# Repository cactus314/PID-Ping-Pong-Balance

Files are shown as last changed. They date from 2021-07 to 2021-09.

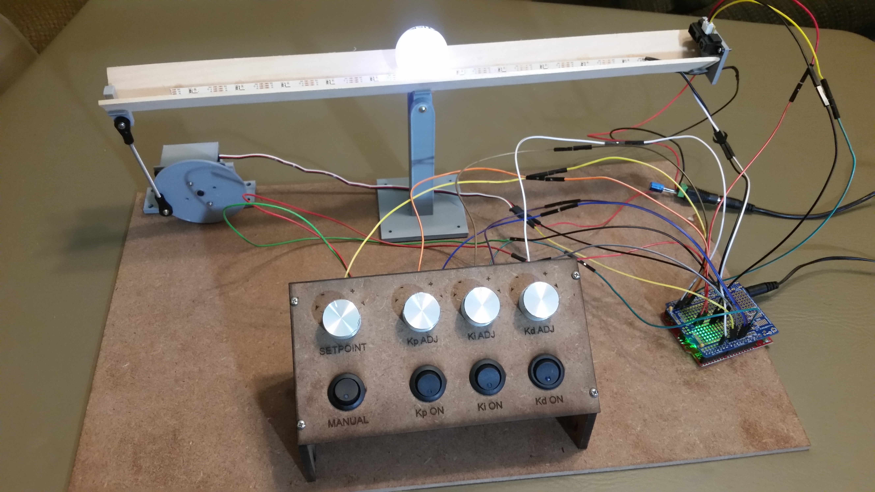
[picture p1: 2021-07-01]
20200308_224231.jpg

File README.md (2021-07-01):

# PID-Ping-Pong-Balance
A PID control demonstration unit, based on a project by Electronoob: http://electronoobs.com/eng_arduino_tut100.php

This project uses an IR sensor to detect the location of a ping-pong ball along a rail and a servo-motor as an actuator to position the angle of the rail to maintain the ball at a given setpoint using hardcoded PID parameters.  The setpoint and P, I, and D gains can also be overridden in "Manual" mode.

A demonstration and explanation of the project is available in the following video:
https://youtu.be/-h1OtBgMqcE

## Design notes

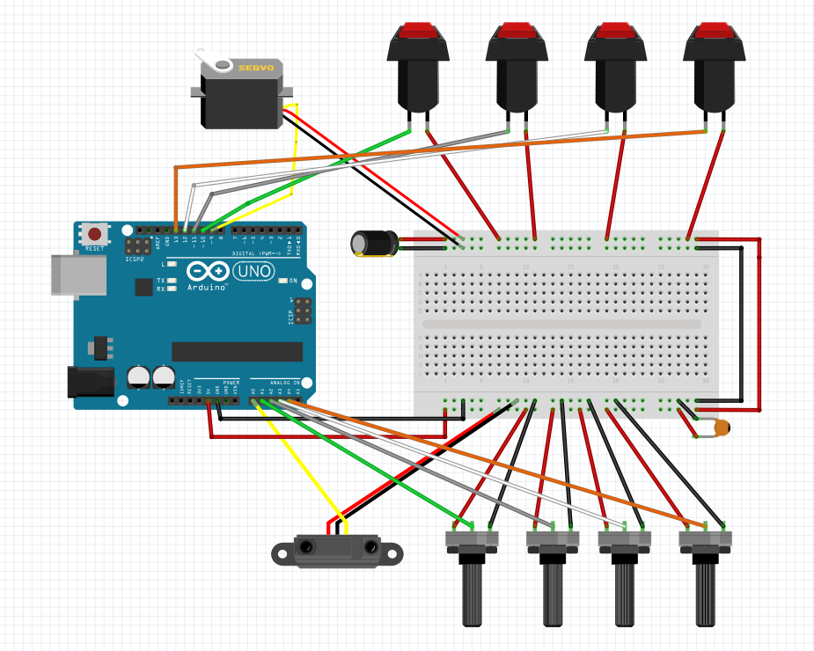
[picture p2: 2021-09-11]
PingPongBalance Fritzing Screenshot.png

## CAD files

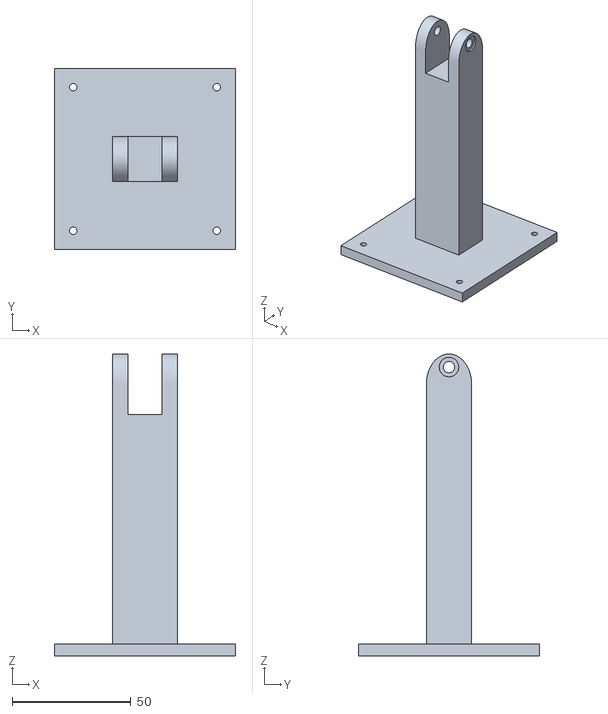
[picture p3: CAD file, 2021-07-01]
PingPongBalanceSTLs/pivot pillar.stl
76.2 x 76.2 x 127.0

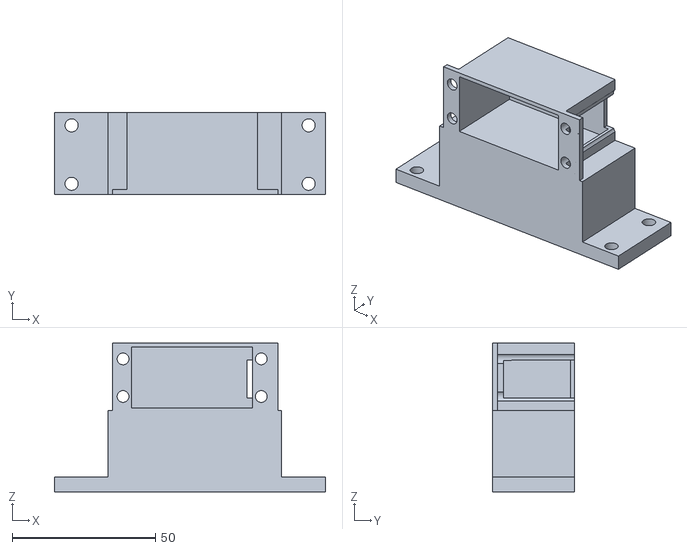
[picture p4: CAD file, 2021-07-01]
PingPongBalanceSTLs/Servo_support_Electronoob.stl
94.6 x 28.7 x 51.9

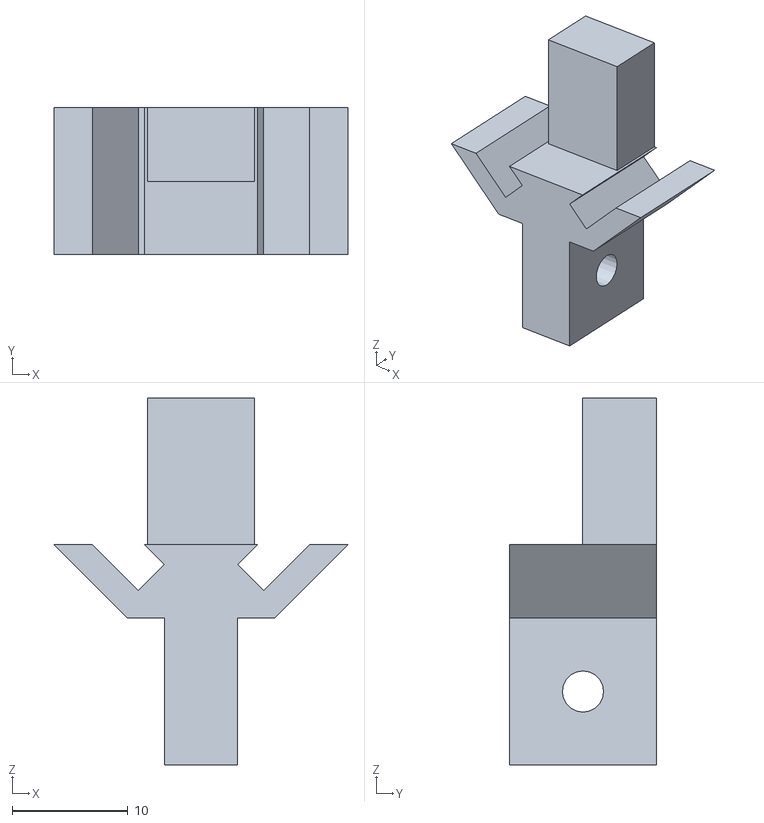
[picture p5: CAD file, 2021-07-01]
PingPongBalanceSTLs/servo end clip.stl
25.4 x 12.7 x 31.7

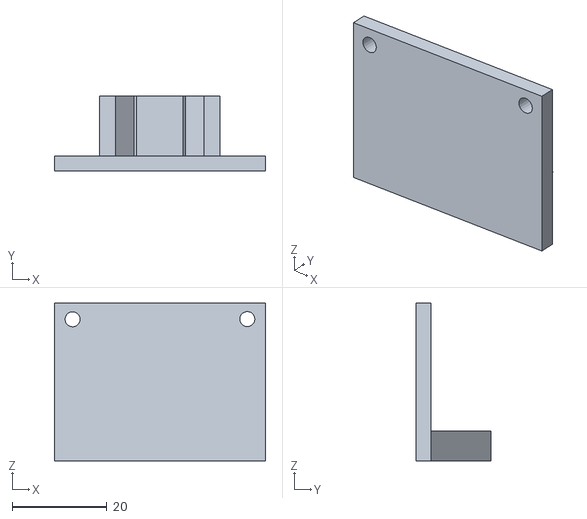
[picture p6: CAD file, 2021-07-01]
PingPongBalanceSTLs/sharp sensor clip.stl
44.6 x 15.9 x 33.3

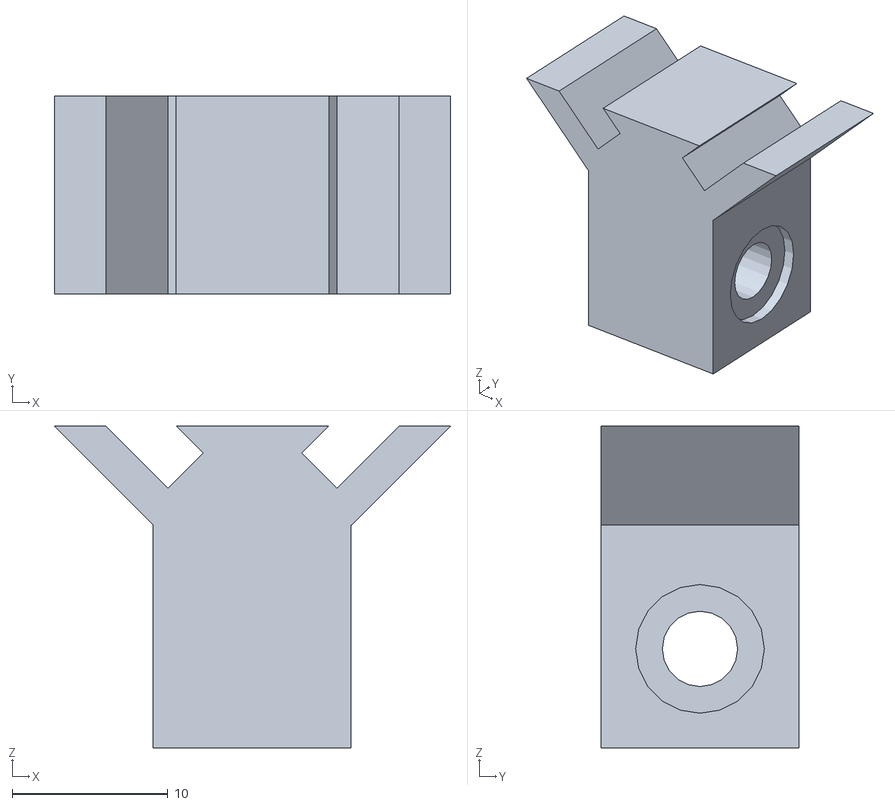
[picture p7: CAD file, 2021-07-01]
PingPongBalanceSTLs/pivot clip.stl
25.4 x 12.7 x 20.6

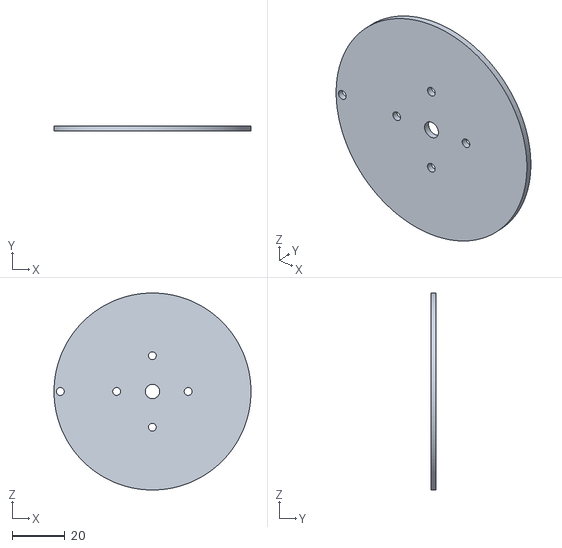
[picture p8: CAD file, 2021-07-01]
PingPongBalanceSTLs/Disc2_Electronoob.stl
74.4 x 2.00 x 74.4

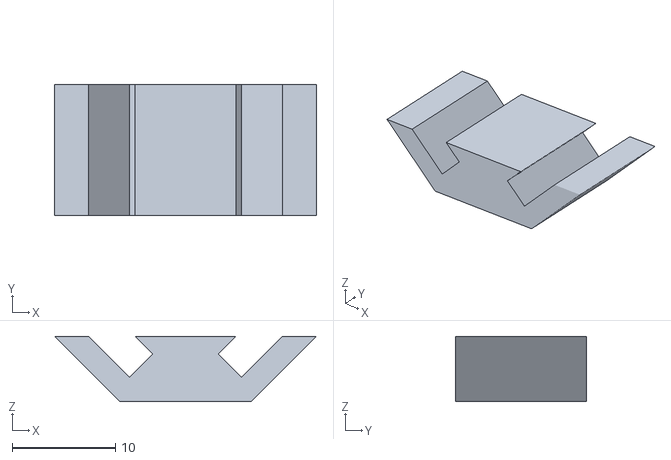
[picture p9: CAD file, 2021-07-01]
PingPongBalanceSTLs/basic clip.stl
25.4 x 12.7 x 6.35

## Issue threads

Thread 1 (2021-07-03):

Need 'ball stop' close to IR sensor

cactus314, 2021-07-03:
The Sharp IR sensor gives bad readings when the ping-pong ball is too close (perhaps 5cm or less).  There should be a mechanical stop so that the ball doesn't so close to the sensor when oscillating back and forth during proportional control.

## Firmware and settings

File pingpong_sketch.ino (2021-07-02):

/*Ping Pong PID Balance
 * March 2020
 * P Ferrell
 * Inspired by: http://www.electronoobs.com/eng_arduino_tut100.php
 * 
 * 
 * */
 
#include <SharpIR.h>  //https://www.makerguides.com/sharp-gp2y0a21yk0f-ir-distance-sensor-arduino-tutorial/
#include <Servo.h>
#include <Adafruit_NeoPixel.h>  //https://learn.adafruit.com/adafruit-neopixel-uberguide/arduino-library-use

#define irPin A0  // IR sensor attached on pin A0
#define irModel 1080  // Sharp IR sensor model GP2Y0A21YK0F
SharpIR SharpIR(irPin,irModel);

#define servoPin 9  // servo motor attached on pin 9
Servo myServo;
int servoDefault = 110; // nominal default position for servo to hold balance rails level
int servoLowerLimit = 20;
int servoUpperLimit = 150;
int servoCorrection = 30;  // value to offset servo if needed

#define NeoPixelPin 6 // NeoPixel control wire attached on pin 6
#define NeoPixelCount 11 // number of NeoPixels on strand
Adafruit_NeoPixel strip(NeoPixelCount, NeoPixelPin, NEO_GRB + NEO_KHZ800);
uint32_t defaultPixelColor = strip.Color(127,127,127); // default color for indicator pixel

// Connections for manual controls
#define manualOveridePin 10 // switch for manual overide
#define kpOnPin 11 // switch to turn on manual Kp
#define kiOnPin 12 // switch to turn on manual Ki
#define kdOnPin 13 // switch to turn on manual Kd
#define setpointInputPin A1 // analog input for setpoint potentiometer
#define kpInputPin A2 // analog input for Kp potentiometer
#define kiInputPin A3 // analog input for Ki potentiometer
#define kdInputPin A4 // analog input for Kd potentiometer
int manualOverideState = 0;
int kpOnState = 0;
int kiOnState = 0;
int kdOnState = 0;


// Physical Constants - **ALL UNITS IN CENTIMETERS (cm)**
float ballDiameter = 0; // (40mm is standard for ping pong balls) **not currently used in code**

// manual setpoint parameters
int midpointIndex = 5; // 6th pixel in strand out of 11
float discreteSetpoints[NeoPixelCount] = {11,7,11,15,19,24,29,33,37,42,46}; //distances in integer cm; note that the first setpoint [0] is larger due to non-linearity of senor; these values will be determined experimentally
int newSetpointIndex = 100; //out of bounds value for initialization

// Default PID Constants  //
float default_Kp = 8;
float default_Ki = 0.2;
float default_Kd = 3500;
float default_setpoint = discreteSetpoints[midpointIndex];
int period = 50;  // refresh rate period of the loop in ms - a guess, and perhaps slightly different for 'manual' vs. 'auto' modes

// PID variables
float Kp; // proportional 
float Ki; // integral 
float Kd; // derivative 
float setpoint = discreteSetpoints[midpointIndex];
float dist; // distance from sensor to ball surface **not ceter of ball**
float distanceError = 0;  // distance from setpoint
float distanceErrorPrevious = 0;
float PID_iWindow = 14; // distanceError must be within +/- this window in cm for PID_i to engage
float PID_p, PID_i, PID_d, PID_total;  // PID correction factors



void setup() {
  pinMode (irPin, INPUT);
  pinMode (setpointInputPin, INPUT);
  pinMode (kpInputPin, INPUT);
  pinMode (kiInputPin, INPUT);
  pinMode (kdInputPin, INPUT);
  pinMode (manualOveridePin, INPUT);
  pinMode (kpOnPin, INPUT);
  pinMode (kiOnPin, INPUT);
  pinMode (kdOnPin, INPUT);

  strip.begin();
  strip.show(); // initialize all NeoPixels to 'off'
  
  myServo.attach(servoPin);
  myServo.write(servoDefault);  // put servo in default position, which should make balance level

}

void loop() {

manualOverideState = digitalRead(manualOveridePin);
if (manualOverideState == HIGH) // 'manual mode' - setpoint, and Kp, Ki, Kd all adjusted from control panel
{
  strip.clear(); 
  int setpointValue = analogRead(setpointInputPin);
  int setpointIndex = map(setpointValue,0,1023,0,10);
  setpoint = discreteSetpoints[setpointIndex];
  strip.setPixelColor(setpointIndex,defaultPixelColor);
  if (newSetpointIndex != setpointIndex) {strip.clear();}
  strip.show();
  newSetpointIndex = setpointIndex;

// set manual Kp
  kpOnState = digitalRead(kpOnPin);
  if (kpOnState == HIGH)
  {
    int KpMultiplier = analogRead(kpInputPin);
    KpMultiplier = map(KpMultiplier, 0,1023,2000,0);
    Kp = default_Kp*KpMultiplier/1000;
  }
  else
  {
    Kp = 0;
  }

// set manual Ki
  kiOnState = digitalRead(kiOnPin);
  if (kiOnState == HIGH)
  {
    int KiMultiplier = analogRead(kiInputPin);
    KiMultiplier = map(KiMultiplier, 0,1023,2000,0);
    Ki = default_Ki*KiMultiplier/1000;
  }
  else
  {
    Ki = 0;
  }
  
// set manual Kd
  kdOnState = digitalRead(kdOnPin);
  if (kdOnState == HIGH)
  {
    int KdMultiplier = analogRead(kdInputPin);
    KdMultiplier = map(KdMultiplier, 0,1023,2000,0);
    Kd = default_Kd*KdMultiplier/1000;
  }
  else
  {
    Kd = 0;
  }
}
else  // manual switch is off and software operating in default auto mode
{
  strip.clear();
  setpoint = default_setpoint;
  Kp = default_Kp;
  Ki = default_Ki;
  Kd = default_Kd;
  strip.setPixelColor(midpointIndex,defaultPixelColor);
  strip.show();
}

  dist = GetDistance(5);  //get distance from IR sensor in cm - input parameter is number of samples to take in average
  distanceError = setpoint - dist;
  PID_p = Kp * distanceError;
  if((-1*PID_iWindow)<distanceError && distanceError<PID_iWindow)
  {
    PID_i = PID_i + (Ki*distanceError);
  }
  else
  {
    PID_i = 0;
  }
  PID_d = Kd*(distanceError-distanceErrorPrevious)/period;
  PID_total = PID_p + PID_i + PID_d;
  distanceErrorPrevious = distanceError;
  ApplyCorrection(PID_total);
}

void ApplyCorrection(float PID_total)  // I pulled this code from electronoobs, but don't fully understand it yet
{
  PID_total = map(PID_total,-150,150,0,160);
  if(PID_total < servoLowerLimit) {PID_total = servoLowerLimit;}
  if(PID_total > servoUpperLimit) {PID_total = servoUpperLimit;}
  myServo.write(PID_total+servoCorrection);
}

float GetDistance(int sampleSize)
// returns distance in integer cm - this is the resolution of the SharpIR sensor
{
  long sum=0;
  for(int i=0;i<sampleSize;i++)
  {
    sum = sum+SharpIR.distance();
  }
  float dist = sum/sampleSize;
  return(dist);
}

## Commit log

2021-07-01 SVGs for laser cutting the control panel
2021-07-01 Sketch for Arduino UNO
2021-07-01 Fritzing diagram of basic circuit.
    Note: Does not show schematic for Neopixel connections (reference the Arduino code) or the preferred use of separate power supplies for the Arduino and servo motor as shown in the demonstration video.
    [PPBalance - Manual Control.fzz]
2021-09-11 Add screeenshot of circuit from Fritzing
